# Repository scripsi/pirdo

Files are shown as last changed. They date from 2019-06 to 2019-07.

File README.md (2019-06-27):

# PiRDO

PiRDO is a Raspberry Pi based client device for the TaRDO delayed radio server. The aim is to create a small, night time bedside radio that is easy to operate by feel alone - no displays, menus or blinky lights - just hardware selector switches, for choosing the station and time delay, and a rotary volume control.

## Hardware

* Raspberry Pi Zero W
* Pimoroni pHAT BEAT DAC/amplifier
* KY-040 type rotary encoder
* 2 x 5-way Fender-style guitar pickup switches
* 4 Ohm, 3W rectangular speaker

## Installing prerequisites

Set up a Raspberry Pi Zero W attached to a Pimoroni Phat-Beat, with a fresh install of Raspbian Lite on the micro SD card. Get it connected to the WiFi network and make sure it is accessible via SSH.

Edit `/boot/config.txt` with tho following changes:

* uncomment `dtparam=i2s=on` to turn on i2s
* comment out `dtparam=audio=on` to turn off the built-in audio
* add `dtoverlay=i2s-mmap` and `dtoverlay=hifiberry-dac` to the end to enable the Phat-Beat's audio.

It should end up looking like this:

```bash
# /boot/config.txt

...

#dtparam=i2c_arm=on
dtparam=i2s=on
#dtparam=spi=on

...

# dtparam=audio=on

...

# For phat-beat
dtoverlay=i2s-mmap
dtoverlay=hifiberry-dac
```

Now get the Pimoroni optimisations and dependencies for the Phat-Beat without the vu-meter stuff:

```bash
curl -sS http://get.pimoroni.com/pulseaudio | bash
```

Create a file `/etc/asound.conf` with the following:

```
pcm.!default {
 type hw
 card 1
}
ctl.!default {
 type hw
 card 1
}
```

Reboot the Pi. Connect a speaker to the Phat-Beat and test it with:

```bash
speaker-test -c2 -t wav
```

If you hear sounds then all is well. Install VLC without x11:

```bash
sudo apt install vlc-nox
```

This installs a metric tonne of other packages (including, confusingly, some x11 ones), but that's still only about half the dependencies of the full `vlc` package!

Test that VLC works:

```bash
vlc http://bbcmedia.ic.llnwd.net/stream/bbcmedia_radio4fm_mf_p
```

With any luck you should hear Radio 4 coming from the speaker! Type CTRL-C to exit.

Install Python 3 PIP and git:

```bash
sudo apt install python3-pip git
```

Then install the Python VLC library:

```bash
sudo pip3 install python-vlc
```

That's all the prerequisites set up!

## Installing and configuring PiRDO

Clone the PiRDO repository from GitHub:

```bash
git clone https://github.com/scripsi/pirdo
```

```bash
sudo nano /lib/systemd/system/pirdo.service
```

```
[Unit]
Description=PiRDO radio
After=multi-user.target

[Service]
ExecStart=/usr/bin/python3 /home/pi/pirdo/pirdo.py

[Install]
WantedBy=multi-user.target
```

```bash
sudo systemctl daemon-reload
sudo systemctl enable pirdo.service
```

```
                 ___
      PB 3.3V  1|o o|2  PB 5V
               3|o o|4
               5|o o|6  
               7|o o|8
      Enc_GND  9|o o|10
GPIO 17 Enc_A 11|o o|12 PB I2S
GPIO 27 Enc_B 13|o o|14
GPIO 22 Enc_C 15|o o|16 PB Data
     Enc_3.3V 17|o o|18 PB Clock
GPIO 10 Sw1_A 19|o o|20 Sw2_GND
GPIO 09 Sw1_B 21|o o|22 Sw2_C GPIO 25
GPIO 11 Sw1_C 23|o o|24 Sw2_B GPIO 08
      Sw1_GND 25|o o|26 Sw2_A GPIO 07
              27|o o|28
     PB F/Fwd 29|o o|30 GND
PB Play/Pause 31|o o|32 PB On/Off
    PB Rewind 33|o o|34 GND
       PB I2S 35|o o|36 PB Vol+
      PB Vol- 37|o o|38
       PB GND 39|o_o|40 PB I2S

PB = Phat Beat
Enc = Encoder
Sw1, Sw2 = Selector switches

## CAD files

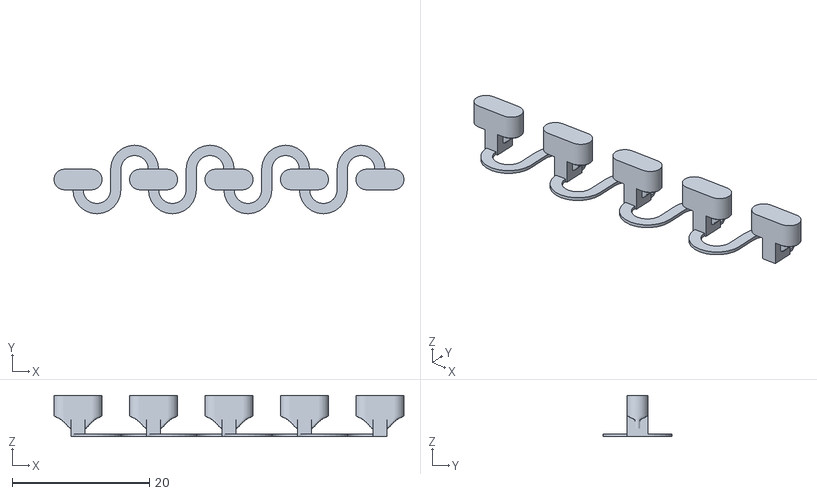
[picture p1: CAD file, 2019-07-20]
case/pirdo-case-rear-btns.stl
51.0 x 10.0 x 6.00

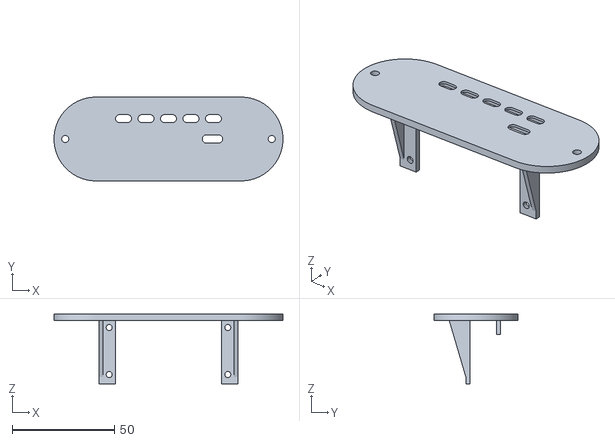
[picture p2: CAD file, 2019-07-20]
case/pirdo-case-rear.stl
112.0 x 41.0 x 34.0

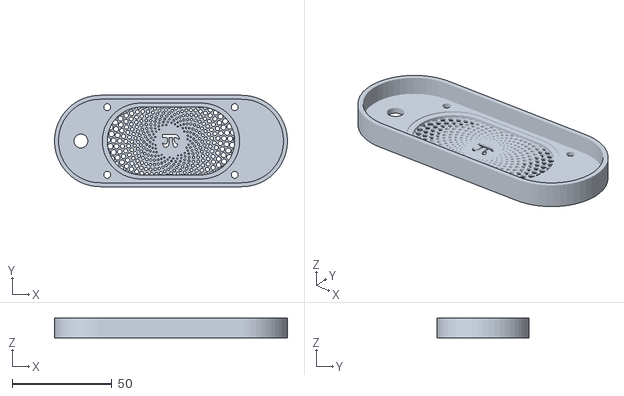
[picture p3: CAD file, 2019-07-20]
case/pirdo-case-front.stl
117.0 x 46.0 x 10.0

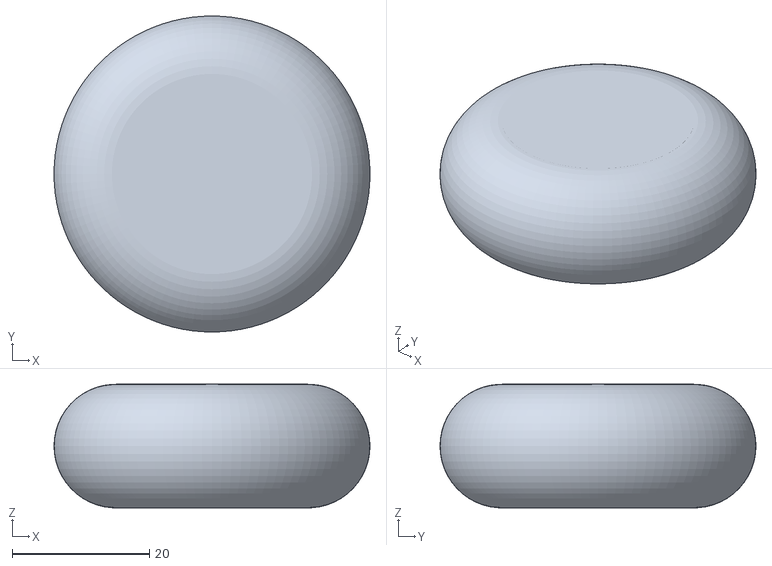
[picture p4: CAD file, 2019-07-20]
case/pirdo-case-vol-knob.stl
46.0 x 46.0 x 18.0

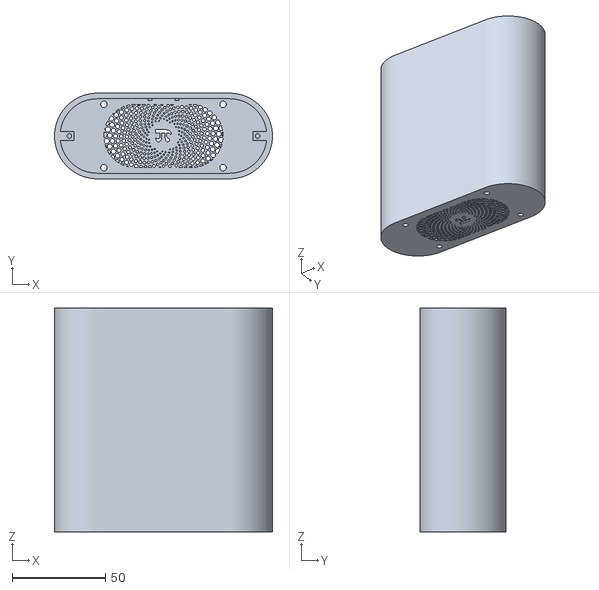
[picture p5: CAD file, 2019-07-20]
case/pirdo-case.stl
117.0 x 46.0 x 120.0

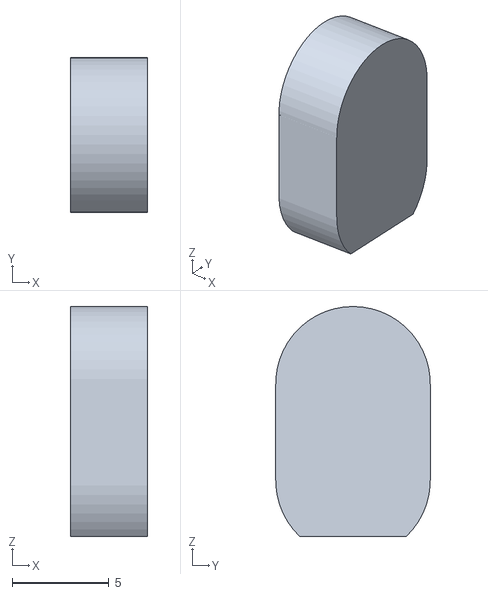
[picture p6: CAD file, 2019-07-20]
case/pirdo-case-sel-knob.stl
4.00 x 8.00 x 11.9

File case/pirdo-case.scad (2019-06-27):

$fa = 15;
$fs = 0.6;
phi = (1 + sqrt(5)) / 2;  // The golden ratio
pi = 3.14159;
imax = 680;

a_bit = 0.01;
a_bit_more = a_bit * 2;

// The dimensions of the front of the speaker cone -
// gives the size of the speaker grille opening
spkr_cone_h = 34;
spkr_cone_w = 64;
spkr_cone_r = spkr_cone_h/2;
spkr_cone_centre_offset = (spkr_cone_w/2) - (spkr_cone_r);

// The dimensions of the felt border around the speaker cone -
// gives the size of the mounting "pad" on which it sits
spkr_border_h = 38;
spkr_border_w = 69;
spkr_border_r = spkr_border_h/2;
spkr_border_centre_offset = (spkr_border_w/2) - (spkr_border_r);
spkr_border_depth = 0.5;

// The distances between the speaker mounting holes
spkr_holes_h = 34;
spkr_holes_w = 64;
spkr_holes_r = 3.5 / 2;

// dimesions of speaker rectangular flange
spkr_w = 71;
spkr_h = 42;

spkr_grille_clearance = 1;
spkr_grille_thickness = 1;
case_front_thickness = spkr_grille_thickness + spkr_grille_clearance + spkr_border_depth;
case_wall_thickness = 2;
case_rear_thickness = 3;

case_outside_h = spkr_h + (case_wall_thickness * 2);
case_outside_r = case_outside_h / 2;
case_outside_w = spkr_w + (case_outside_r * 2);
case_side_offset = (spkr_w / 2);
case_outside_d = 120;

case_inside_h = spkr_h;
case_inside_r = case_inside_h / 2;
case_inside_w = spkr_w + (case_inside_r * 2);

crm_w = 9;
crm_h = 5;
crm_d = 6;
crm_offset_w = (case_outside_w / 2) - case_wall_thickness - 6;
crm_hole_r = 2.5 / 2;
crm_hole_d = 5;

sw_offset_d = 40;
sw_offset_w = spkr_holes_w / 2;
sw_holes_d = 41;
sw_holes_r = 3.5 / 2;
sw_slot_w = 2;
sw_slot_d = 23;


// The raspberry pi mounting holes
pi_supp_w = 8;
pi_supp_d = 34;
pi_supp_h = 10;
pi_supp_thickness = 2;
pi_holes_w = 58;
pi_holes_d = 23;
pi_holes_clearance_z = 3.5;
pi_holes_r = 3 / 2;
pi_supp_offset_x = (pi_holes_w / 2) + (pi_supp_thickness / 2);
pi_supp_offset_z = case_outside_d - (pi_supp_d / 2);
pi_supp_offset_y = (pi_supp_thickness / 2) - 5;
pi_holes_offset_x = pi_holes_w / 2;
pi_holes_offset_y = pi_supp_offset_y + pi_supp_thickness;
pi_holes_offset_z = case_outside_d - case_rear_thickness - pi_holes_clearance_z;

usb_hole_offset_x = 21.5;
usb_hole_offset_y = pi_supp_offset_y + 4;
usb_rebate_thickness = 1;
usb_rebate_depth = case_rear_thickness - usb_rebate_thickness;

pb_supp_w = 5;
pb_supp_d = 10;
pb_supp_thickness = 2;
pb_holes_clearance_z = 3.5;
pb_holes_r = 3 / 2;
pb_holes_w = 58;
pb_supp_offset_x = pb_holes_w / 2;
pb_supp_offset_z = case_outside_d - (pb_supp_d / 2);
pb_supp_offset_y = pi_supp_offset_y + 15;
pb_holes_offset_x = pb_holes_w / 2;
pb_holes_offset_y = pb_supp_offset_y + pb_supp_thickness;
pb_holes_offset_z = case_outside_d - case_rear_thickness - pb_holes_clearance_z;


btns_w = 4;
btns_r = 1.5;
btns_d = 3;
btns_pitch = 11;
btns_rebate_thickness = 1;
btns_rebate_depth = case_rear_thickness - btns_rebate_thickness;
btns_striker_w = 2;
btns_striker_h = 3;
btns_striker_d = btns_rebate_depth + 1;
btns_clearance_r = btns_r + 0.4;
btns_offset_y=pi_supp_offset_y+14;
btns_spring_h=0.4;
btns_spring_d=1.5;
btns_spring_r=2.75;


vol_r = 7 / 2;
vol_fence_thickness = 2;
vol_fence_w = 12.4 + vol_fence_thickness;
vol_fence_h=2;
vol_d = 12;
vol_tab_r = 1.5;
vol_tab_h = 1;
vol_tab_offset_d=6;

* front_face();
* side_walls();
* rear_face();
* buttons();

vol_knob();
* sel_knob();

module front_face() {
  // Construct the front face
  difference() {

    // the front plate
    stadium(radius=case_outside_r, length=spkr_w, height=case_front_thickness, quality=100);
    
    // Remove the speaker grille holes
    intersection() {
    
      // Speaker grille outline
      translate([0,0,-a_bit])
        stadium(radius=spkr_cone_r, length=spkr_cone_centre_offset*2, height=spkr_grille_thickness + a_bit_more, quality=50);
        
      // Speaker grille holes - a golden spiral
      union() {
        for (i = [160:imax]) {
          th = i * 360 * phi * 20;
          r = i* 0.05;
          x = r * sin(th);
          y = r * cos(th);
          translate([x, y, -a_bit]) 
              cylinder(h = spkr_grille_thickness + a_bit_more, r = i * 0.0023);
        }
      
      // Pi symbol  
      translate([0,0,-a_bit])
        linear_extrude(spkr_grille_thickness + a_bit_more)
          mirror([1,0,0])
            text("\u03C0", font="GFS Didot:style=Bold", halign="center", valign="center");
      }
      
    }
    
    // remove the speaker cutout behind the grille
    translate([0,0,spkr_grille_thickness])
      stadium(radius=spkr_cone_r, length=spkr_cone_centre_offset*2, height=case_front_thickness, quality=50);
  
    // remove the speaker mounting border
    translate([0,0,spkr_grille_thickness + spkr_grille_clearance])
      stadium(radius=spkr_border_r, length=spkr_border_centre_offset*2, height=spkr_border_depth * 2, quality=50);
  
    // remove the speaker mounting holes
    union() {
      translate([-spkr_holes_w / 2, -spkr_holes_h / 2, -case_front_thickness / 2])
        cylinder(h=case_front_thickness * 2, r=spkr_holes_r);
      translate([spkr_holes_w / 2, -spkr_holes_h / 2, -case_front_thickness / 2])
        cylinder(h=case_front_thickness * 2, r=spkr_holes_r);
      translate([spkr_holes_w / 2, spkr_holes_h / 2, -case_front_thickness / 2])
        cylinder(h=case_front_thickness * 2, r=spkr_holes_r);
      translate([-spkr_holes_w / 2, spkr_holes_h / 2, -case_front_thickness / 2])
        cylinder(h=case_front_thickness * 2, r=spkr_holes_r);
    }
  }
  
}

module side_walls() {
// Construct the side walls

  

  difference() {
    // create the body
    stadium(radius=case_outside_r, length=spkr_w, height=case_outside_d, quality=100);
    
    // cut out the interior
    translate([0,0,-a_bit])
      stadium(radius=case_inside_r, length=spkr_w, height=case_outside_d+a_bit_more, quality=100);
    
    // cut out switch mountings
    
    // switch slots
    translate([sw_offset_w,case_inside_r-a_bit,sw_offset_d]) 
      rotate([-90,90,0])
        stadium(radius=sw_slot_w/2, length = sw_slot_d, height = case_wall_thickness + a_bit_more, quality = 20);
    translate([-sw_offset_w,case_inside_r-a_bit,sw_offset_d]) 
      rotate([-90,90,0])
        stadium(radius=sw_slot_w/2, length = sw_slot_d, height = case_wall_thickness + a_bit_more, quality = 20);
    
    // switch screw holes
    translate([sw_offset_w, case_inside_r-a_bit, sw_offset_d-(sw_holes_d/2)]) 
      rotate([-90,0,0])
        cylinder(r = sw_holes_r, h = case_wall_thickness + a_bit_more);
    translate([sw_offset_w, case_inside_r-a_bit, sw_offset_d+(sw_holes_d/2)]) 
      rotate([-90,0,0])
        cylinder(r = sw_holes_r, h = case_wall_thickness + a_bit_more);
    translate([-sw_offset_w, case_inside_r-a_bit, sw_offset_d-(sw_holes_d/2)]) 
      rotate([-90,0,0])
        cylinder(r = sw_holes_r, h = case_wall_thickness + a_bit_more);
    translate([-sw_offset_w, case_inside_r-a_bit, sw_offset_d+(sw_holes_d/2)]) 
      rotate([-90,0,0])
        cylinder(r = sw_holes_r, h = case_wall_thickness + a_bit_more);
        
    // cut out volume encoder mounting hole
    translate([0, case_inside_r-a_bit, sw_offset_d]) 
      rotate([-90,0,0])
        cylinder(r = vol_r, h = case_wall_thickness + a_bit_more);
    // cut out volume encoder tab recess
    translate([0, case_inside_r-a_bit, sw_offset_d-vol_tab_offset_d]) 
      rotate([-90,0,0])
        cylinder(r = vol_tab_r, h = vol_tab_h + a_bit);
   
    }
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

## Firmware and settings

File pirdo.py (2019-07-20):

# *** Imports ***

import vlc
import time
import gpiozero
import queue
import configparser

# *** Globals ***
volume=50
player=vlc.MediaPlayer("")
eventq = queue.Queue(maxsize=10)

# read volume config if available
vconfig = configparser.ConfigParser()
vconfig.read('/home/pi/pirdo/volume.ini')
if vconfig['DEFAULT']['volume']:
    volume = int(vconfig['DEFAULT']['volume'])

# read vstations config if available
sconfig = configparser.ConfigParser()
sconfig.read('/home/pi/pirdo/stations.ini')

stations = [vlc.Media(sconfig['SW2A']['A']),
            vlc.Media(sconfig['SW2A']['B']),
            vlc.Media(sconfig['SW2A']['C']),
            vlc.Media(sconfig['SW2A']['D']),
            vlc.Media(sconfig['SW2A']['E']),
            vlc.Media(sconfig['SW2B']['A']),
            vlc.Media(sconfig['SW2B']['B']),
            vlc.Media(sconfig['SW2B']['C']),
            vlc.Media(sconfig['SW2B']['D']),
            vlc.Media(sconfig['SW2B']['E']),
            vlc.Media(sconfig['SW2C']['A']),
            vlc.Media(sconfig['SW2C']['B']),
            vlc.Media(sconfig['SW2C']['C']),
            vlc.Media(sconfig['SW2C']['D']),
            vlc.Media(sconfig['SW2C']['E']),
            vlc.Media(sconfig['SW2D']['A']),
            vlc.Media(sconfig['SW2D']['B']),
            vlc.Media(sconfig['SW2D']['C']),
            vlc.Media(sconfig['SW2D']['D']),
            vlc.Media(sconfig['SW2D']['E']),
            vlc.Media(sconfig['SW2E']['A']),
            vlc.Media(sconfig['SW2E']['B']),
            vlc.Media(sconfig['SW2E']['C']),
            vlc.Media(sconfig['SW2E']['D']),
            vlc.Media(sconfig['SW2E']['E'])]

# Setup controls
enc_a = gpiozero.Button(17)         # Rotary encoder pin A connected to GPIO17
enc_b = gpiozero.Button(27)         # Rotary encoder pin B connected to GPIO27
enc_c = gpiozero.Button(22)         # Rotary encoder push button connected to GPIO22

sw1_a = gpiozero.DigitalInputDevice(10,pull_up=True)
sw1_b = gpiozero.DigitalInputDevice(9,pull_up=True)
sw1_c = gpiozero.DigitalInputDevice(11,pull_up=True)

sw2_a = gpiozero.DigitalInputDevice(7,pull_up=True)
sw2_b = gpiozero.DigitalInputDevice(8,pull_up=True)
sw2_c = gpiozero.DigitalInputDevice(25,pull_up=True)

# *** Definitions ***

# Event handler definitions

def enc_a_rising():                    # Pin A event handler
    if enc_b.is_pressed: eventq.put('VOLDN')   # pin A rising while B is active is a clockwise turn

def enc_b_rising():                    # Pin B event handler
    if enc_a.is_pressed: eventq.put('VOLUP')    # pin B rising while A is active is a clockwise turn

def enc_c_released():                    # Pin C event handler
    eventq.put('VOLPRESS')

def sw1_changed():
    eventq.put('SW1')

def sw2_changed():
    eventq.put('SW2')

def read_sw1():
    sw1_state=0
    if sw1_a.value:
        if sw1_b.value:
            if sw1_c.value:
                sw1_state=0
            else:
                sw1_state=4
        else:
            if sw1_c.value:
                sw1_state=0
            else:
                sw1_state=5
    else:
        if sw1_b.value:
            if sw1_c.value:
                sw1_state=2
            else:
                sw1_state=3
        else:
            if sw1_c.value:
                sw1_state=1
            else:
                sw1_state=0
    return sw1_state

def read_sw2():
    sw2_state=0
    if sw2_a.value:
        if sw2_b.value:
            if sw2_c.value:
                sw2_state=0
            else:
                sw2_state=4
        else:
            if sw2_c.value:
                sw2_state=0
            else:
                sw2_state=5
    else:
        if sw2_b.value:
            if sw2_c.value:
                sw2_state=2
            else:
                sw2_state=3
        else:
            if sw2_c.value:
                sw2_state=1
            else:
                sw2_state=0
    return sw2_state

def get_station_number():
  sw1_pos = read_sw1()
  sw2_pos = read_sw2()
  snum = sw1_pos + ((sw2_pos - 1) * 5)
  return snum

# Register event handlers
enc_a.when_pressed = enc_a_rising      # Register the event handler for pin A
enc_b.when_pressed = enc_b_rising      # Register the event handler for pin B
enc_c.when_released = enc_c_released      # Register the event handler for pin C

sw1_a.when_activated = sw1_changed
sw1_a.when_deactivated = sw1_changed
sw1_b.when_activated = sw1_changed
sw1_b.when_deactivated = sw1_changed
sw1_c.when_activated = sw1_changed
sw1_c.when_deactivated = sw1_changed

sw2_a.when_activated = sw2_changed
sw2_a.when_deactivated = sw2_changed
sw2_b.when_activated = sw2_changed
sw2_b.when_deactivated = sw2_changed
sw2_c.when_activated = sw2_changed
sw2_c.when_deactivated = sw2_changed

# *** Init ***
current_station=get_station_number()
if current_station:
    player.set_media(stations[current_station-1])
    player.audio_set_volume(volume)
    player.play()
    playing = True
    
while True:
    if playing:
        if not player.is_playing():
            player.play()
            time.sleep(5)
    if eventq.not_empty:
        event = eventq.get()
        if event == 'VOLDN':
            volume -= 1
            if volume < 0:
                volume = 0
            player.audio_set_volume(volume)
        elif event == 'VOLUP':
            volume += 1
            if volume > 100:
                volume = 100
            player.audio_set_volume(volume)
        elif event == 'VOLPRESS':
            if playing:
                player.stop()
                playing = False
                vconfig['DEFAULT']['volume'] = str(volume)
                with open('/home/pi/pirdo/volume.ini', 'w') as configfile:
                    vconfig.write(configfile)
            else:
                player.play()
                playing = True
        elif event == 'SW1':
            new_station = get_station_number()
            if new_station:
                if new_station != current_station:
                    current_station = new_station
                    player.stop()
                    player.set_media(stations[current_station-1])
                    player.play()
        elif event == 'SW2':
            new_station = get_station_number()
            if new_station:
                if new_station != current_station:
                    current_station = new_station
                    player.stop()
                    player.set_media(stations[current_station-1])
                    player.play()

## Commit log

2019-06-09 Added encoder test
2019-06-09 Updated encoder to add push button and event queue
2019-06-10 Changed pins for encoder
2019-06-10 Changed encoder pins
2019-06-10 Fixed position of event handlers
    [pirdo.py]
2019-06-10 Fixed integer conversion of read_sw1 result
    [pirdo.py]
2019-06-10 Try again with the function fix
    [pirdo.py]
2019-06-11 Adapted for KY-040 encoder
2019-06-20 Added case design OpenSCAD file
    [pirdo-case.scad]
2019-06-27 Added config and case design
    [pirdo-case.scad]
2019-06-27 Fixed str conversion ov volume on save
    [pirdo.py]
2019-06-27 Added retry on play failure
    [pirdo.py]
2019-07-20 Added stations.ini and case designs
    [pirdo-case-front.stl, pirdo-case-rear-btns.stl, pirdo-case-rear.stl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]
2019-07-20 Added debug print statement to get_station_number
2019-07-20 Fixed station number calculation
    [pirdo.py]
